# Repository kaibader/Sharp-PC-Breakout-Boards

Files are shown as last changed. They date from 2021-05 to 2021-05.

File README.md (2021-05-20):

# Sharp-PC-Breakout-Boards
Various Breakout Boards for the Sharp PC-1500/1600 Series

## 40-Pin Cartridge Breakout Boards for the Sharp PC-1500/1600 Series

### v1.0
I've ported the two breakout boards from EagleCAD to KiCad.
The design of two breakout boards was also slightly improved.
There is no functional difference to the older revisions.

### v0.1
Initial release, designed in EagleCAD (which I'm not using anymore).

## Breakout Board for 60 Pin Connector of the Sharp PC-1500/PC-1600 Series
The breakout board was designed to allow easy access to all pins of the Sharp PC connector.

### v1.0
Upated the connector layout: Fixed an issue with a falsely documented FGND pin. Slight improvements in the layout.

### v0.2
Replaced the 1.27 mm pin header: the HIF6A-60PA-1.27DS is compatible with the discontinued JAE PICL-60P-LT (original Sharp-PC connector).
The whole PCB was redesigned: functional units (e.g. data bus, address bus) are now combined.

### v0.1
Initial release, based on a 1.27 mm pin header. Designed in EagleCAD (which I'm not using anymore).

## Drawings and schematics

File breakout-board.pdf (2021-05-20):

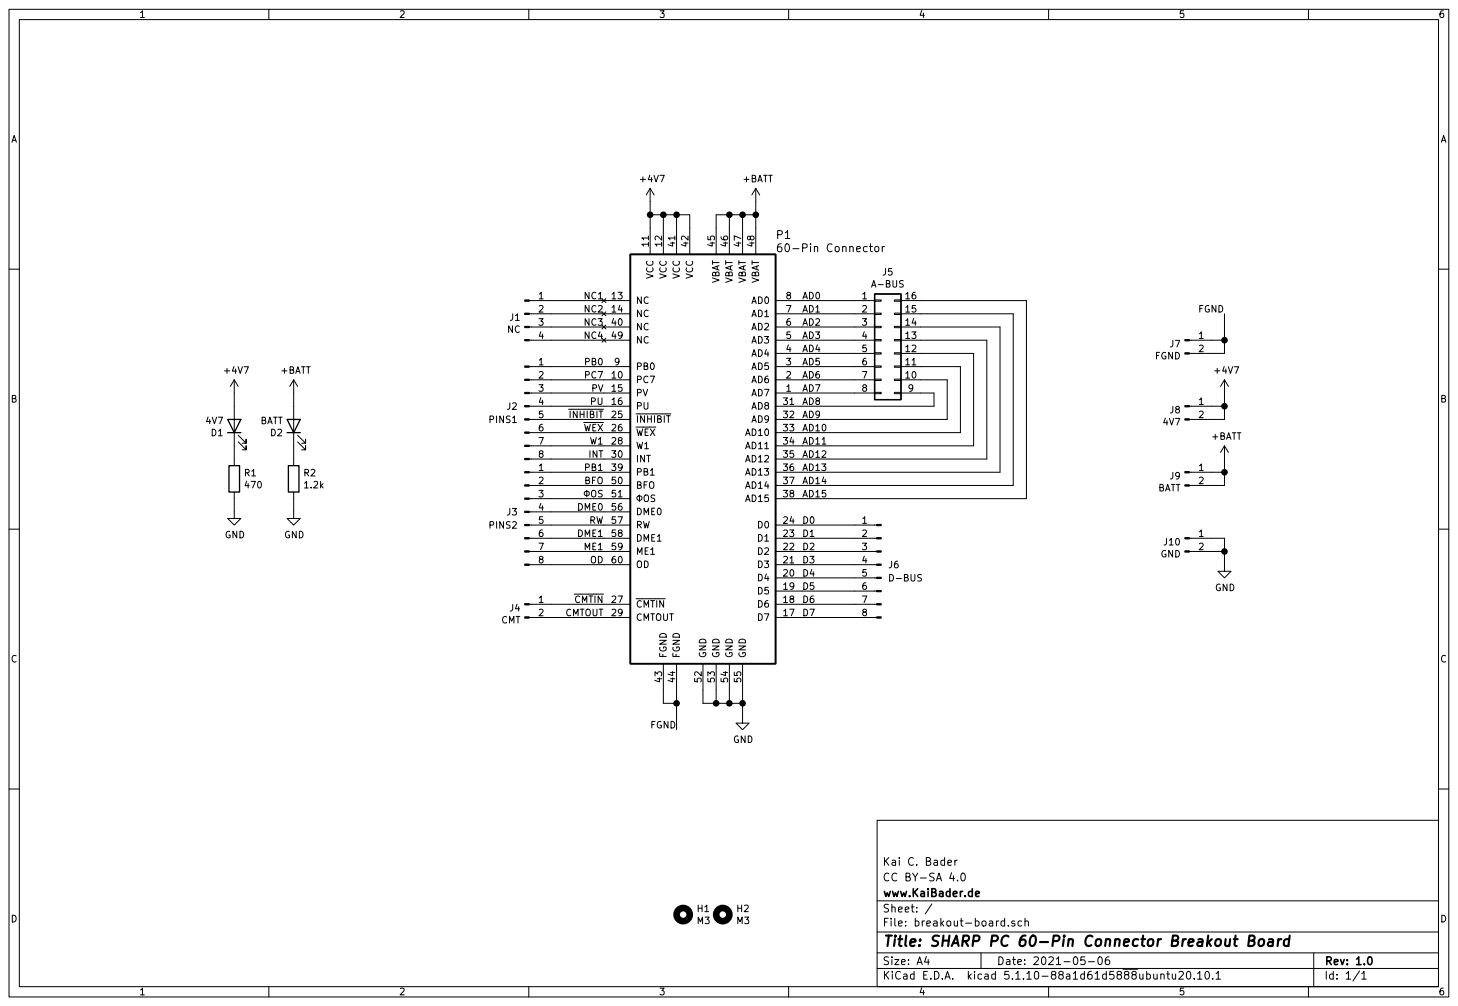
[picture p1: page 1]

2 | 15
3 | 14
4 | 13
5 | 12
6 | 11
7 | 10

File: breakout-board.sch Sheet: / www.KaiBader.de CC BY-SA 4.0 Kai C. Bader

Id: 1/1 Title: SHARP PC 60-Pin Connector Breakout Board

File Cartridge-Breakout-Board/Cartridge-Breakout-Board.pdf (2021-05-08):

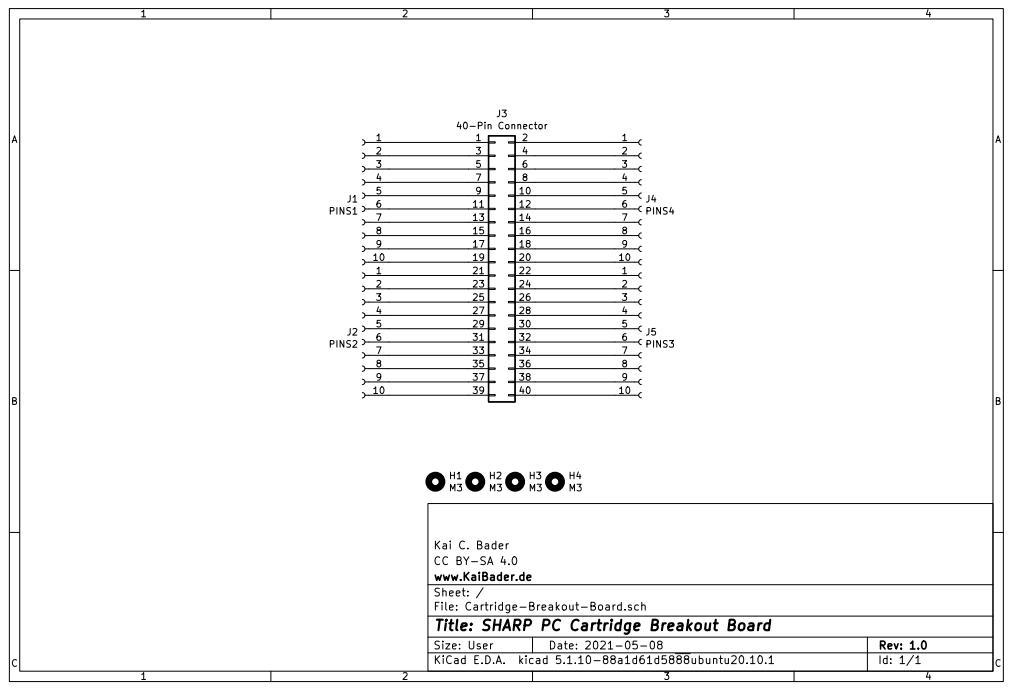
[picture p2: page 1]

File: Cartridge-Breakout-Board.sch Sheet: / www.KaiBader.de CC BY-SA 4.0 Kai C. Bader 1

Id: 1/1 Title: SHARP PC Cartridge Breakout Board

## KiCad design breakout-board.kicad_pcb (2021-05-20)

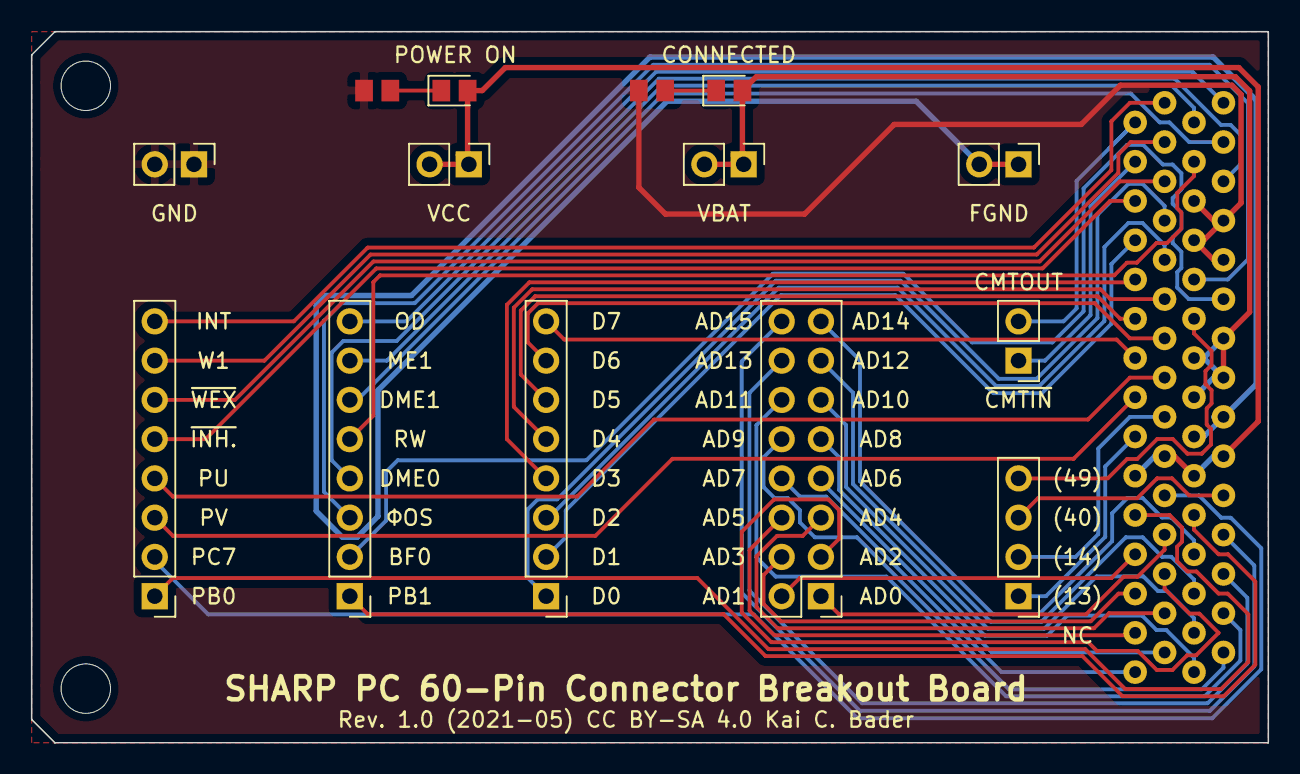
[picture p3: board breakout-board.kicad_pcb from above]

Board: 2 copper layers, 80.0 x 46.0 mm, 17 parts (0 on the bottom side), 52 nets.

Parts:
D1: 4V7; LED_0805_2012Metric
D2: BATT; LED_0805_2012Metric
H1, H2: M3; MountingHole_3.2mm_M3
J1: NC; PinHeader_1x04_P2.54mm_Vertical
J2: PINS1; PinHeader_1x08_P2.54mm_Vertical
J3: PINS2; PinHeader_1x08_P2.54mm_Vertical
J4: CMT; PinHeader_1x02_P2.54mm_Vertical
J5: A-BUS; PinHeader_2x08_P2.54mm_Vertical
J6: D-BUS; PinHeader_1x08_P2.54mm_Vertical
J7: FGND; PinHeader_1x02_P2.54mm_Vertical
J8: 4V7; PinHeader_1x02_P2.54mm_Vertical
J9: BATT; PinHeader_1x02_P2.54mm_Vertical
J10: GND; PinHeader_1x02_P2.54mm_Vertical
P1: 60-Pin Connector; HIF6A-60PA-1.27DS
R1: 470; R_0805_2012Metric
R2: 1.2k; R_0805_2012Metric

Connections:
+4V7: D1.2, J8.1, J8.2, P1.11, P1.12, P1.41, P1.42
+BATT: D2.2, J9.1, J9.2, P1.45, P1.46, P1.47, P1.48
/AD0: J5.1, P1.8
/AD1: J5.2, P1.7
/AD2: J5.3, P1.6
/AD3: J5.4, P1.5
/AD4: J5.5, P1.4
/AD5: J5.6, P1.3
/AD6: J5.7, P1.2
/AD7: J5.8, P1.1
/AD8: J5.9, P1.31
/AD9: J5.10, P1.32
/AD10: J5.11, P1.33
/AD11: J5.12, P1.34
/AD12: J5.13, P1.35
/AD13: J5.14, P1.36
/AD14: J5.15, P1.37
/AD15: J5.16, P1.38
/BFO: J3.2, P1.50
/CMTOUT: J4.2, P1.29
/D0: J6.1, P1.24
/D1: J6.2, P1.23
/D2: J6.3, P1.22
/D3: J6.4, P1.21
/D4: J6.5, P1.20
/D5: J6.6, P1.19
/D6: J6.7, P1.18
/D7: J6.8, P1.17
/DME0: J3.4, P1.56
/DME1: J3.6, P1.58
/FGND: J7.1, J7.2, P1.43, P1.44
/INT: J2.8, P1.30
/ME1: J3.7, P1.59
/NC1: J1.1, P1.13
/NC2: J1.2, P1.14
/NC3: J1.3, P1.40
/NC4: J1.4, P1.49
/OD: J3.8, P1.60
/PB0: J2.1, P1.9
/PB1: J3.1, P1.39
/PC7: J2.2, P1.10
/PU: J2.4, P1.16
/PV: J2.3, P1.15
/RW: J3.5, P1.57
/W1: J2.7, P1.28
/~CMTIN: J4.1, P1.27
/~INHIBIT: J2.5, P1.25
/~WEX: J2.6, P1.26
/ΦOS: J3.3, P1.51
GND: J10.1, J10.2, P1.52, P1.53, P1.54, P1.55, R1.2, R2.2
unnamed: D1.1, R1.1
unnamed: D2.1, R2.1

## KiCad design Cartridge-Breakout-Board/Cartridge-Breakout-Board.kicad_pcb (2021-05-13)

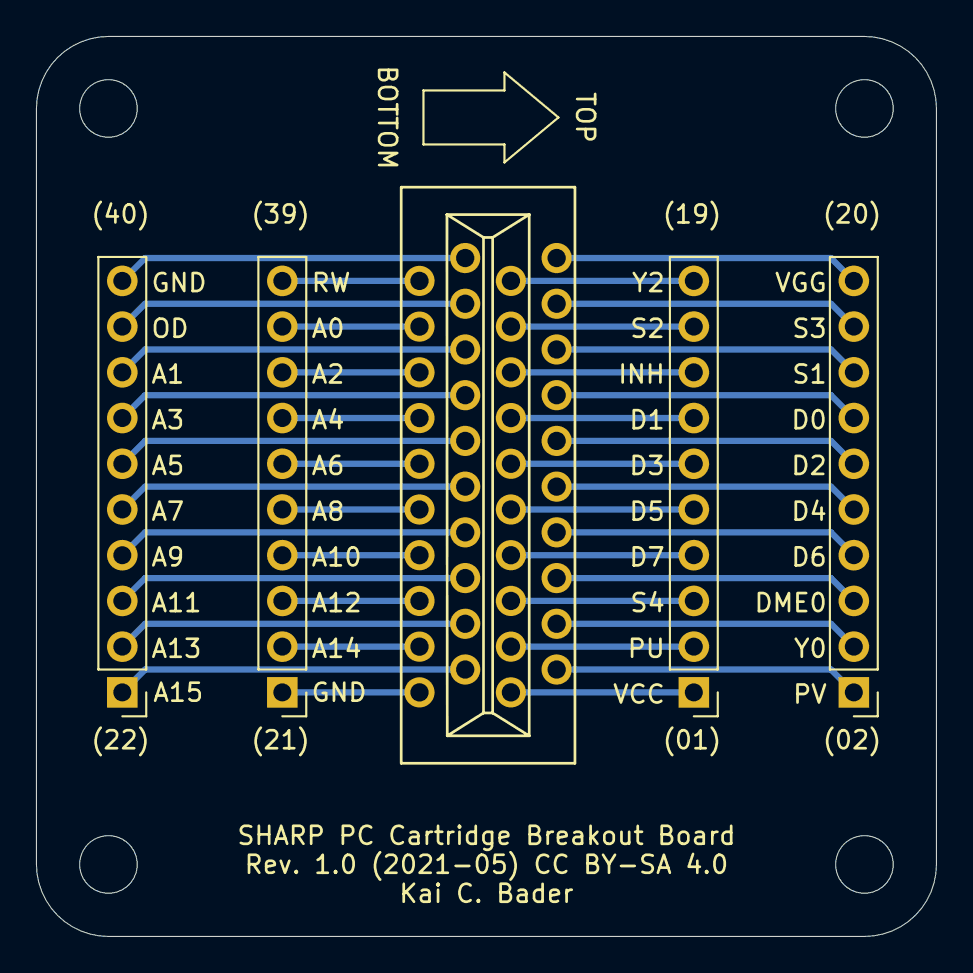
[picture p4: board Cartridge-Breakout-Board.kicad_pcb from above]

Board: 2 copper layers, 50.0 x 50.0 mm, 9 parts (0 on the bottom side), 40 nets.

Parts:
H1, H2, H3, H4: M3; MountingHole_3.2mm_M3
J1: PINS1; PinHeader_1x10_P2.54mm_Vertical
J2: PINS2; PinHeader_1x10_P2.54mm_Vertical
J3: 40-Pin Connector; KLS1-503-40-S
J4: PINS4; PinHeader_1x10_P2.54mm_Vertical
J5: PINS3; PinHeader_1x10_P2.54mm_Vertical

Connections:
unnamed: J1.1, J3.1
unnamed: J1.2, J3.3
unnamed: J1.3, J3.5
unnamed: J1.4, J3.7
unnamed: J1.5, J3.9
unnamed: J1.6, J3.11
unnamed: J1.7, J3.13
unnamed: J1.8, J3.15
unnamed: J1.9, J3.17
unnamed: J1.10, J3.19
unnamed: J2.1, J3.21
unnamed: J2.2, J3.23
unnamed: J2.3, J3.25
unnamed: J2.4, J3.27
unnamed: J2.5, J3.29
unnamed: J2.6, J3.31
unnamed: J2.7, J3.33
unnamed: J2.8, J3.35
unnamed: J2.9, J3.37
unnamed: J2.10, J3.39
unnamed: J3.2, J4.1
unnamed: J3.4, J4.2
unnamed: J3.6, J4.3
unnamed: J3.8, J4.4
unnamed: J3.10, J4.5
unnamed: J3.12, J4.6
unnamed: J3.14, J4.7
unnamed: J3.16, J4.8
unnamed: J3.18, J4.9
unnamed: J3.20, J4.10
unnamed: J3.22, J5.1
unnamed: J3.24, J5.2
unnamed: J3.26, J5.3
unnamed: J3.28, J5.4
unnamed: J3.30, J5.5
unnamed: J3.32, J5.6
unnamed: J3.34, J5.7
unnamed: J3.36, J5.8
unnamed: J3.38, J5.9
unnamed: J3.40, J5.10

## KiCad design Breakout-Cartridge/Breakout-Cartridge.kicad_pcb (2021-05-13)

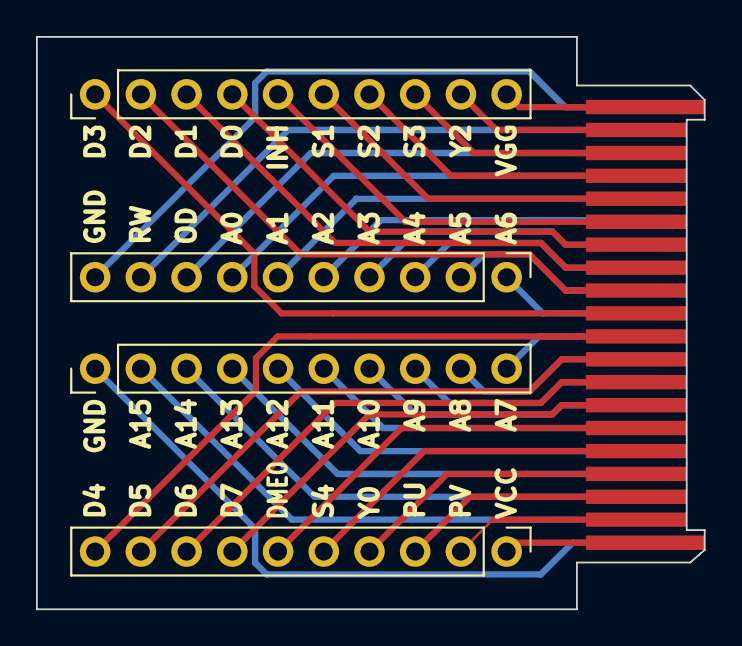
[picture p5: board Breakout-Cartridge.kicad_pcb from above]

Board: 2 copper layers, 37.1 x 31.8 mm, 5 parts (0 on the bottom side), 40 nets.

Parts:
J1: PINS1; PinHeader_1x10_P2.54mm_Vertical
J2: PINS2; PinHeader_1x10_P2.54mm_Vertical
J3: 40-Pin Connector; SHARP-PC-CARTRIDGE
J4: PINS4; PinHeader_1x10_P2.54mm_Vertical
J5: PINS3; PinHeader_1x10_P2.54mm_Vertical

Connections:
unnamed: J1.1, J3.1
unnamed: J1.2, J3.2
unnamed: J1.3, J3.3
unnamed: J1.4, J3.4
unnamed: J1.5, J3.5
unnamed: J1.6, J3.6
unnamed: J1.7, J3.7
unnamed: J1.8, J3.8
unnamed: J1.9, J3.9
unnamed: J1.10, J3.10
unnamed: J2.1, J3.11
unnamed: J2.2, J3.12
unnamed: J2.3, J3.13
unnamed: J2.4, J3.14
unnamed: J2.5, J3.15
unnamed: J2.6, J3.16
unnamed: J2.7, J3.17
unnamed: J2.8, J3.18
unnamed: J2.9, J3.19
unnamed: J2.10, J3.20
unnamed: J3.21, J4.1
unnamed: J3.22, J4.2
unnamed: J3.23, J4.3
unnamed: J3.24, J4.4
unnamed: J3.25, J4.5
unnamed: J3.26, J4.6
unnamed: J3.27, J4.7
unnamed: J3.28, J4.8
unnamed: J3.29, J4.9
unnamed: J3.30, J4.10
unnamed: J3.31, J5.1
unnamed: J3.32, J5.2
unnamed: J3.33, J5.3
unnamed: J3.34, J5.4
unnamed: J3.35, J5.5
unnamed: J3.36, J5.6
unnamed: J3.37, J5.7
unnamed: J3.38, J5.8
unnamed: J3.39, J5.9
unnamed: J3.40, J5.10

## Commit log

2016-04-16 Added The Eagle files for the Breakout Boards to a Git repository.
    [expansion.GBL, expansion.GBO, expansion.GBP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]
2018-06-13 Housekeeping
    - Moved the v0.1 breakout board to a separate directory.
    - Prepared everything for a new (KiCad) based design.
    [expansion.GBL, expansion.GBO, expansion.GBP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]
2018-06-13 Created project files in KiCad
    [breakout-board.kicad_pcb, breakout-board.sch]
2018-06-20 Created a new version of the 60-pin Breakout Board for the Sharp PC.
    [breakout-board.kicad_pcb, breakout-board.sch, expansion.kicad_pcb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]
2018-06-20 Added a few labels
    [breakout-board.kicad_pcb]
2018-06-23 Various updates
    [breakout-board.kicad_pcb]
2018-06-23 Created gerber files of the v0.2 design.
    [breakout-board.drl, breakout-board.gbl, breakout-board.gbs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]
2018-06-23 Some housekeeping
    [expansion.GBL, expansion.GBO, expansion.GBP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]
2021-05-06 Rev. 1.0 of the Sharp PC-1500 60-Pin Connector Breakout Board.
    Squashed commit of various design updates.
    Fixed one falsely documented FGND pin.
    [breakout-board-B_Cu.gbr, breakout-board-B_Mask.gbr, breakout-board-Edge_Cuts.gbr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]
2021-05-08 Updated the two 40-Pin Breakout Boards.
    Ported the boards from EagleCAD to KiCad.
    Slightly improved the board layouts.
    No functional updates.
    [Breakout-Cartridge-B_Cu.gbr, Breakout-Cartridge-B_Mask.gbr, Breakout-Cartridge-B_SilkS.gbr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]
2021-05-13 Updated the Gerber files.
    [Breakout-Cartridge-B_Cu.gbl, Breakout-Cartridge-B_Mask.gbs, Breakout-Cartridge-B_Paste.gbp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]

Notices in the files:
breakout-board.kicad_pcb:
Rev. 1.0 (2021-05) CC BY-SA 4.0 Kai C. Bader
